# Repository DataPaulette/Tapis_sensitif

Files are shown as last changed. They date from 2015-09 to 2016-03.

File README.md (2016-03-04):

# /Tapis_sensitif/
 - Date : 13/08/2015
 - Project : http://datapaulette.org/Tapis_sensitif/
 - Repository : https://github.com/DataPaulette/Tapis_sensitif/
 
This project is under construction, all codes are work in progress. 

#/Tapis_sensitif/I2C_network_processing/
This folder include à processing sketch allowing mapping to trigger MIDI notes.
The following contributed libraries are needed :
 - theMidiBus
 - controlP5
 - (Linux) To alow non-root users permission to use the Teensy device you will nead to install udev rule file : http://www.pjrc.com/teensy/td_download.html

#/Tapis_sensitif/I2C_matrix_MASTER/
https://www.arduino.cc/en/Main/Software
This folder include the Arduino code for the master device plugged on a computer via USB port.
You will also need to install the teensy plugin for Arduino :
https://www.pjrc.com/teensy/teensyduino.html

#/Tapis_sensitif/I2C_matrix_SLAVE/
This folder include the Arduino code for each sensitive slave device that communicate over a four wire I2C bus.
The following contributed libraries are needed :
 - elapsedMillis

#/Tapis_sensitif/Eagle_board/
This folder include the Eagle source code of the electronic board made for the project.
http://www.cadsoftusa.com/download-eagle/
The file 7_BIT_ARRAY_COUNT.csv is useful to configure the dip switch of each board.
This 7 bit dip switch is used to configure the address of each board.

#Confugure the Midi server
 - Linux START virtal midi : modprobe snd-virmidi 
  - use QjackCtl to do the midi routing
 - MacOs ??
 - Windows ??

#TODO
 - ix the LOAD end SAVE fonction under MacOs
 - RPC library for arduino !?
 - The DIP switch on the PCB can be replace with a simple solderable traces.
 - Add optimized link state routing protocol :
  - https://fr.wikipedia.org/wiki/Optimized_link_state_routing_protocol
  - http://tools.ietf.org/html/rfc3626
  - https://github.com/moussu/GLiP/tree/master/source/Source

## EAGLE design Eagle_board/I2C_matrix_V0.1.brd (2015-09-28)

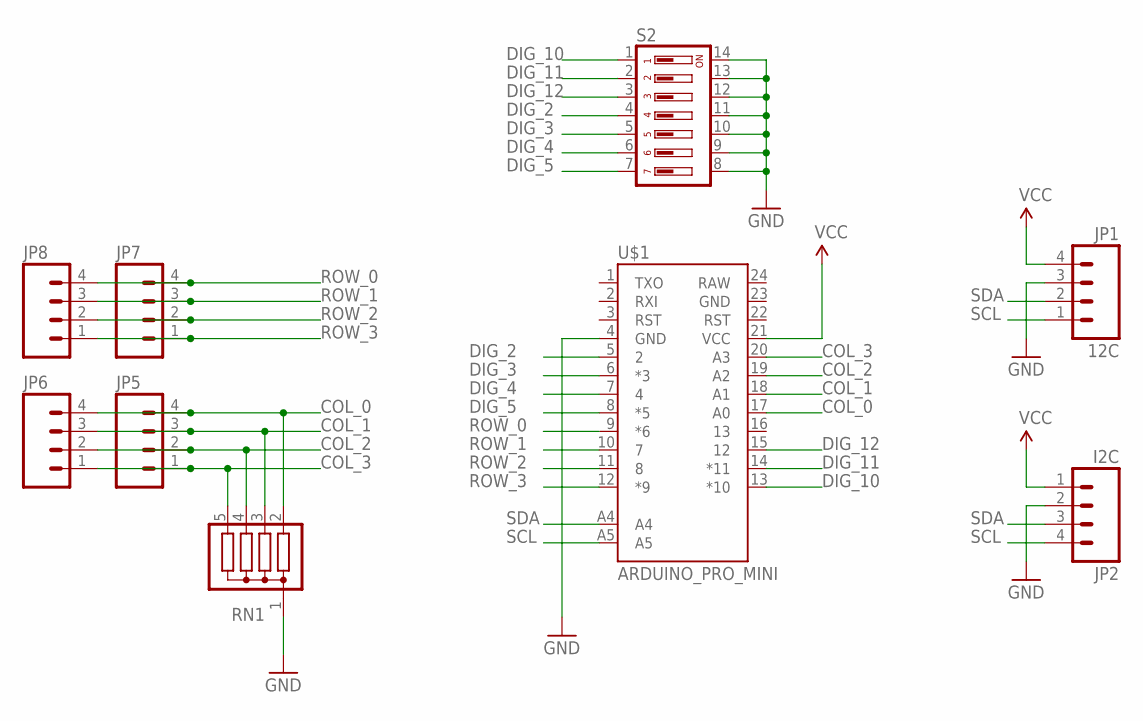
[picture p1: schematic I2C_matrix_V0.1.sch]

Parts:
JP1: 12C; 1X04-SMD_LONG
JP2: I2C; 1X04-SMD_LONG
JP5, JP6, JP7, JP8: M04LONGPADS; 1X04_LONGPADS
RN1: G04R; SIL5
S2: DIP07YL
U$1: ARDUINO_PRO_MINI

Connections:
COL_0: JP5.4, JP6.4, RN1.2, U$1.17 (A0)
COL_1: JP5.3, JP6.3, RN1.3, U$1.18 (A1)
COL_2: JP5.2, JP6.2, RN1.4, U$1.19 (A2)
COL_3: JP5.1, JP6.1, RN1.5, U$1.20 (A3)
DIG_2: S2.4, U$1.5 (2)
DIG_3: S2.5, U$1.6 (*3)
DIG_4: S2.6, U$1.7 (4)
DIG_5: S2.7, U$1.8 (*5)
DIG_10: S2.1, U$1.13 (*10)
DIG_11: S2.2, U$1.14 (*11)
DIG_12: S2.3, U$1.15 (12)
GND: JP1.3, JP2.2, RN1.1, S2.8, S2.9, S2.10, S2.11, S2.12, S2.13, S2.14, U$1.4 (GND)
ROW_0: JP7.4, JP8.4, U$1.9 (*6)
ROW_1: JP7.3, JP8.3, U$1.10 (7)
ROW_2: JP7.2, JP8.2, U$1.11 (8)
ROW_3: JP7.1, JP8.1, U$1.12 (*9)
SCL: JP1.1, JP2.4, U$1.A5
SDA: JP1.2, JP2.3, U$1.A4
VCC: JP1.4, JP2.1, U$1.21 (VCC)

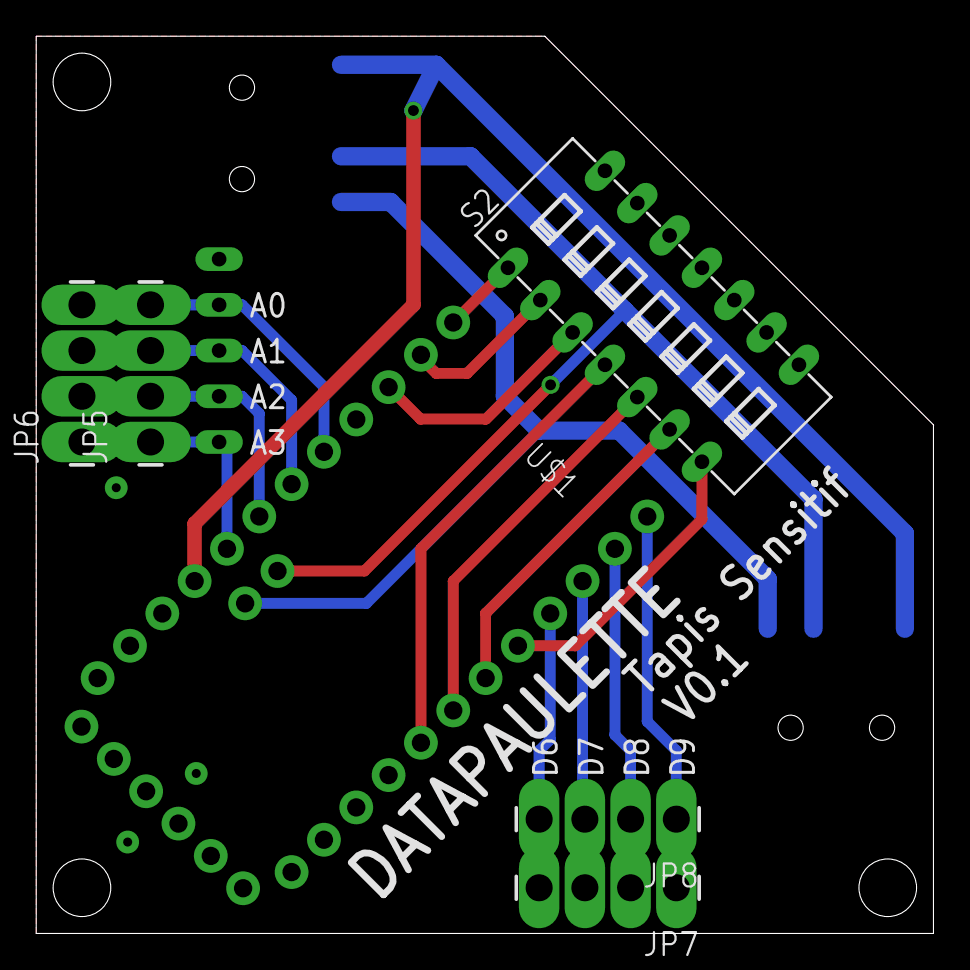
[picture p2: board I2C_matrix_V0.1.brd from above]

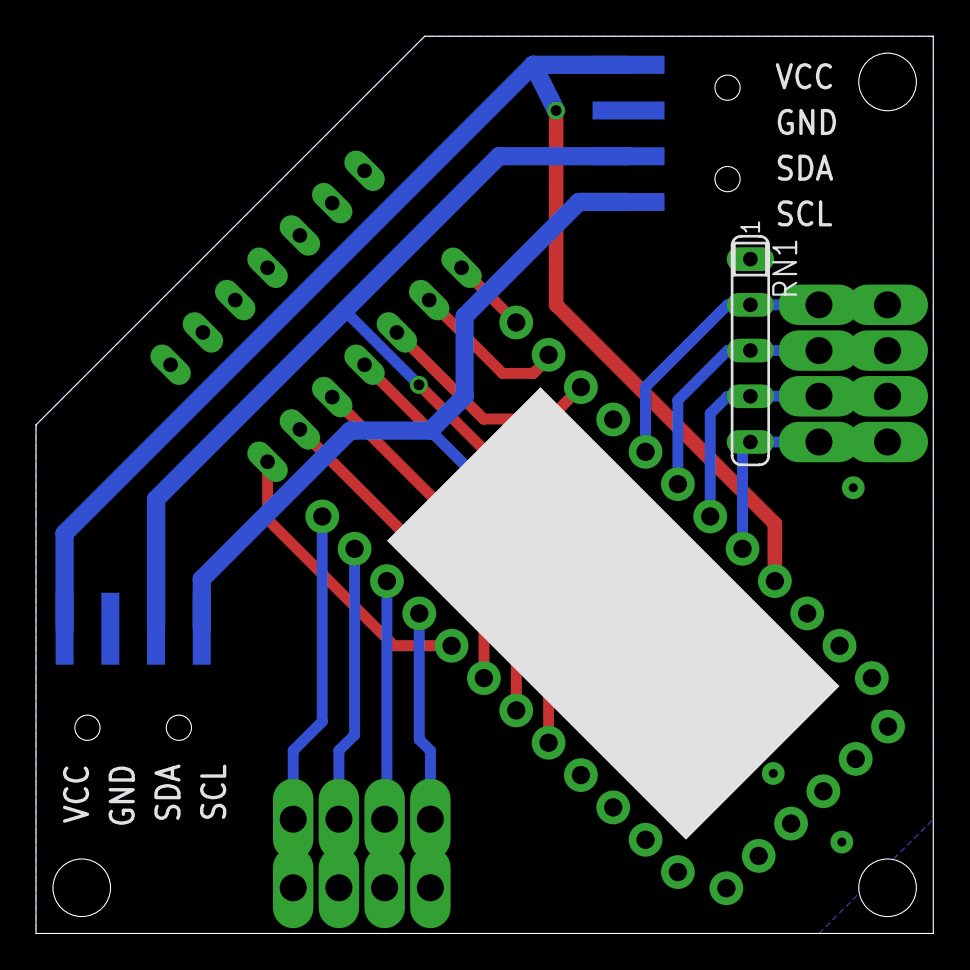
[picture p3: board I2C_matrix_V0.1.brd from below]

Board: 2 copper layers, 49.8 x 49.8 mm, 9 parts (3 on the bottom side), 19 nets.

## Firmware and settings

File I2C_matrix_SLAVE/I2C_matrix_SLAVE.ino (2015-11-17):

// Maurin Donneaud : maurin@datapaulette.org
// 4x4 e-textile matrix for Arduino I2C bus based
// I2C bus based A4 (SDA), A5 (SCL)
// licence GPL V2.0
// Arduino Pro or Pro Mini
// ATmega328 (5V - 16MHz)

#include <elapsedMillis.h>
#include <Wire.h>

elapsedMillis elapsedTime; // declare global if you don't want it reset every time loop runs

#define  BAUD_RATE         115200

#define  ROWS              3           // define how many rows on the matrix sensor
#define  COLS              3           // define how many columns on the matrix sensor
#define  PAYLOAD_SIZE      ROWS*COLS*2 // bytes expected to be received by the master I2C master
#define  LED_PIN           13          // define the LED pin
#define  FRAME_RATE        5           // elapsed time between each sensor reading
#define  DIL_SWITCH        7           // number of switchis on the DIL-switch

byte  NODE_ADDRESS  =      0;          // set a unique address for each I2C slave node
byte incomingByte = 0;
byte nodePayload[ PAYLOAD_SIZE ];

// digital pins array
const int dilSwitch[ DIL_SWITCH ] = {
  10, 11, 12, 2, 3, 4, 5
};

// Dig pins array
const int rowPins[ ROWS ] = {
  8, 7, 6
  // 6, 7, 8
};

// Analog pins array
const int columnPins[ COLS ] = {
  A1, A2, A3
  // A3, A2, A1
};

unsigned long lastFrameTime = 0;
int value = 0;

boolean toggleLed = false;
boolean USB_TRANSMIT = false;
boolean DEBUG_NODE_ADDRESS = false;

/////////////////////// INITIALISATION
void setup() {

  pinMode( LED_PIN, OUTPUT );          // Set rows pins in high-impedance state
  if ( USB_TRANSMIT ) Serial.begin( BAUD_RATE );            // start serial for output

  for ( int i = 0; i < DIL_SWITCH; i++ ) {
    pinMode( dilSwitch[ i ], INPUT_PULLUP ); // Set dilSwitch pins as input and activate pullUps resistors
  }
  setNodeID();

  if ( !USB_TRANSMIT ) Wire.begin( NODE_ADDRESS );          // join i2c bus with address #8
  if ( !USB_TRANSMIT ) Wire.onRequest( requestEvent );      // register event

  for ( int i = 0; i < ROWS; i++ ) {
    pinMode( rowPins[ i ], INPUT );    // Set rows pins in high-impedance state
  }

  blinkBlink( 21 );
}

//////////////////////////////////////////////////////////// BOUCLE PRINCIPALE
void loop() {

  for ( int row = 0; row < ROWS; row++ ) {
    // Set row pin as output (+3V)
    pinMode( rowPins[ row ], OUTPUT );
    digitalWrite( rowPins[ row ], HIGH );

    for ( int column = 0; column < COLS; column++ ) {

      if ( elapsedTime >= FRAME_RATE ) {
        elapsedTime = 0;              // reset the counter to 0 so the counting starts over...

        // int sensorID = row * COLS + column;
        // sensorID = sensorID * 2;

        int sensorID = column * ROWS + row;
        sensorID = sensorID * 2;

        value = analogRead( columnPins[ column ] );

        nodePayload[ sensorID ] = value & B01111111;                // lowByte
        nodePayload[ sensorID + 1 ] = ( value >> 7 ) & B00000111;   // highByte

        if ( USB_TRANSMIT ) Serial.print( value ), Serial.print( '\t' );
      }
    }
    // Set row pin in high-impedance state
    pinMode( rowPins[ row ], INPUT );
    if ( USB_TRANSMIT ) Serial.println();
  }
  if ( USB_TRANSMIT ) Serial.println();
}

// function that executes whenever data is requested by master
// this function is registered as an event, see setup()
void requestEvent() {
  Wire.write( nodePayload, PAYLOAD_SIZE );
}

void blinkBlink( int times ) {
  for ( int i = 0; i < times; i++ ) {
    digitalWrite( LED_PIN, toggleLed );
    delay( 60 );
    toggleLed = !toggleLed;
  }
}

void setNodeID() {

  for ( int i = 0; i < DIL_SWITCH; i++) {

    int bitVal = digitalRead( dilSwitch[ i ] );

    if ( bitVal == HIGH) {
      bitClear( NODE_ADDRESS, i );
    } else {
      bitSet( NODE_ADDRESS, i );
    }
  }
  if ( DEBUG_NODE_ADDRESS ) Serial.println( NODE_ADDRESS );
}

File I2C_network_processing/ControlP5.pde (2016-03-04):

////////// Setup the menu
void setupMenu( ScrollableList ddl ) {
  String available_output[];
  int itemHeight = 30;
  int itemWidth = 250;

  ddl.setBarHeight( itemHeight );
  ddl.setItemHeight( itemHeight );

  if ( ddl == p1 ) {
    ddl.setPosition( 0, 0); ////////////////////////////////////////////// ERROR
    ddl.setCaptionLabel( "USB PORT" );
    for ( int i=0; i<Serial.list ().length; i++ ) {
      String portName = Serial.list()[ i ];
      p1.addItem( portName, i );
    }  
    ddl.setSize( itemWidth, Serial.list().length/2 * itemHeight );  //
  }

  if ( ddl == p2 ) {
    ddl.setPosition( X_SCREN_SIZE - menuXsize, 0); ////////////////////////////////////////////// ERROR
    ddl.setCaptionLabel( "MIDI PORT" );
    available_output = outgoing.availableOutputs(); // Returns an array of available output devices
    for ( int i=0; i<available_output.length; i++ ) {
      String portName = available_output[ i ];
      p2.addItem( portName, i );
    }
    ddl.setSize( itemWidth, available_output.length * itemHeight + itemHeight );  //
  }
  ddl.setBackgroundColor( color(10, 15, 0) );
  ddl.setColorBackground( color(100, 105, 100) );
  ddl.close();
}

////////// Get the port number 
void controlEvent( ControlEvent theEvent ) {
  int BAUD_RATE = 115200;
  int portValue = 0;
  String USB_PORT = "none";
  String MIDI_PORT = "none";

  if ( theEvent.isController() ) {

    //////////////////////////////////////////////////////////// USB PORT
    if ( theEvent.controller().getName() == "usbPort" ) {
      portValue = ( int ) theEvent.controller().getValue();
      USB_PORT = Serial.list()[ portValue ];

      try {
        myPort = new Serial( this, USB_PORT, BAUD_RATE );
        println( "USB_DEVICES : " + USB_PORT );
        myPort.write( DEVICES );
        p1.setColorBackground( color( 10, 255, 0 ) );
        load( FILE ); // BUGGED
      }
      catch ( Exception e ) {
        fill( 255, 0, 0 );
        textAlign( CENTER );
        textSize( X_SCREN_SIZE/8 );
        text("WRONG USB", X_SCREN_SIZE/2, Y_SCREN_SIZE/2 );
        println( "WRONG USB PORT : " + USB_PORT );
        p1.setColorBackground( color( 255, 105, 100 ) );
      }
    }

    //////////////////////////////////////////////////////////// MIDI PORT
    if ( theEvent.controller().getName() == "midiPort" ) {
      portValue = ( int ) theEvent.controller().getValue();
      MIDI_PORT = outgoing.availableOutputs()[ portValue ];

      try {
        outgoing = new MidiBus( this, -1, MIDI_PORT ); // Create a new MidiBus with no input device and one output device.
        println( "MIDI_DEVICES : " + MIDI_PORT );
        p2.setColorBackground( color( 10, 255, 0 ) );
      }
      catch ( Exception e ) { ///////////////////////// FIXME
        fill( 255, 0, 0 );
        textAlign( CENTER );
        textSize( X_SCREN_SIZE/8 );
        text( "WRONG MIDI", X_SCREN_SIZE/2, Y_SCREN_SIZE/2 );
        println( "WRONG MIDI PORT : " + MIDI_PORT );
        p2.setColorBackground( color( 255, 105, 100 ) );
      }
    }
  }
}

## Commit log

2015-08-13 added i2C master
2015-08-13 added I2C slave
2015-08-13 added processing mapping soft
    [saved_2_2.csv]
2015-08-13 added eagle board
    [I2C_matrix_V0.1.brd, I2C_matrix_V0.1.sch]
2015-08-13 added Arduino code for onboard Dill Switch
    [I2C_matrix_V0.1.brd]
2015-08-13 added 7-BIT array count
    [7_BIT_ARRAY_COUNT.csv]
2015-08-15 Processing 3 compatibility
    [I2C_matrix_V0.1.brd]
2015-08-16 clean up
    [saved_2_2.csv]
2015-08-29 Improved midibus
    [saved.csv]
2015-09-28 add GERBER files
    [I2C_matrix_V0.1.brd, I2C_matrix_V0.1.sch, saved.csv]
2015-10-10 fix midi output
    [saved.csv]
2015-10-11 added Processing 3 support, improved midi OUT
    [saved.csv]
2015-10-11 BUG FIX
    [saved.csv]
2015-10-26 added libraries
    [saved.csv]
2015-11-17 Update for the presentation
    [saved.csv]
2016-01-19 last update
    [7_BIT_ARRAY_COUNT.csv, saved.csv]

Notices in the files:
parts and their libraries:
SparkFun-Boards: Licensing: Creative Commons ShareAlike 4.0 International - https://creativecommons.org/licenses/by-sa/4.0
